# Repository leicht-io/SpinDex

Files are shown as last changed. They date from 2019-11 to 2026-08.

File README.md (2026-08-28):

# SpinDex
SpinDex is a small RPM measurement tool for the Beogram 4000 series.
The main focus is to verify that the turntable is restored correctly and maintains the correct speed over an extended period.
The code is written to run on the M5Stack StampS3 (ESP32-S3) but could easily be ported to other microcontrollers and architectures.

This mono repository is divided into multiple sub-repositories, explained below:

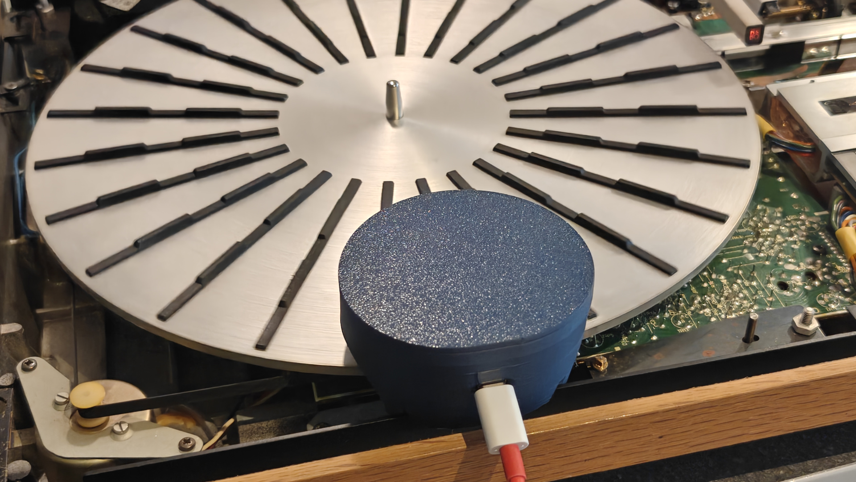
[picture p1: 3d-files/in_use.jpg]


### 3D Files (3d-files):
This folder contains all the 3D models.
- spindex_bottom.stl
- spindex_top.stl

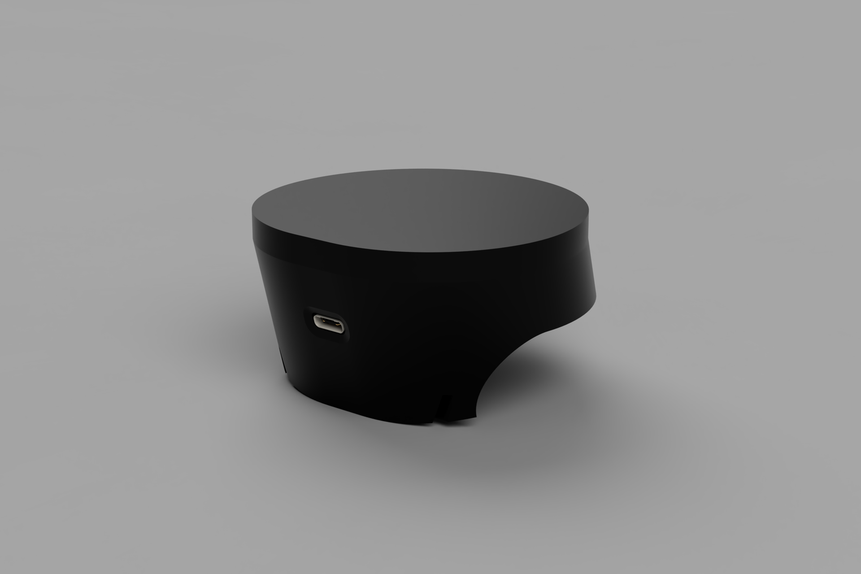
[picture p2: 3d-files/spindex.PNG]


---

### Web App (web-app)
This folder contains the web app. It connects to the controller over Bluetooth (Web Bluetooth — Chrome/Edge on desktop or Android, no install needed) and displays the live RPM as a temporal line graph. It's hosted publicly, free to use, at **https://spindex.leicht.io/**.

Features:
- Pair with the controller over Web Bluetooth, with automatic reconnect on a dropped connection so an unattended run rides out a transient disconnect.
- Start/stop tracking sessions, persisted locally in the browser (IndexedDB) — a page refresh or reconnect doesn't lose the running session.
- Keep multiple tracking sessions around and switch between them from the Trackings list, including revisiting past (stopped) sessions.
- Name a tracking when starting it, or rename it later from the Trackings list.
- Live stat tiles for current/average/max RPM and % deviation from the nominal 33⅓/45 RPM target, colour-coded by how far off spec.
- Selectable chart time window (Live 10 min / 1h / 6h / 12h / 24h / All), auto-bucketed to a fixed point budget so even a 24h session stays smooth to render.
- Gap-aware charting — a BLE disconnect or closed tab shows as a clearly marked gap in the plot rather than a misleading flat or interpolated line.
- CSV export of any tracking session for offline analysis.
- Delete old tracking sessions.
- Single dark, "precision-instrument" themed UI.

Unit tests for the pure logic (chart bucketing/gap detection, CSV export) run via `npm test`, see `web-app/package.json`.

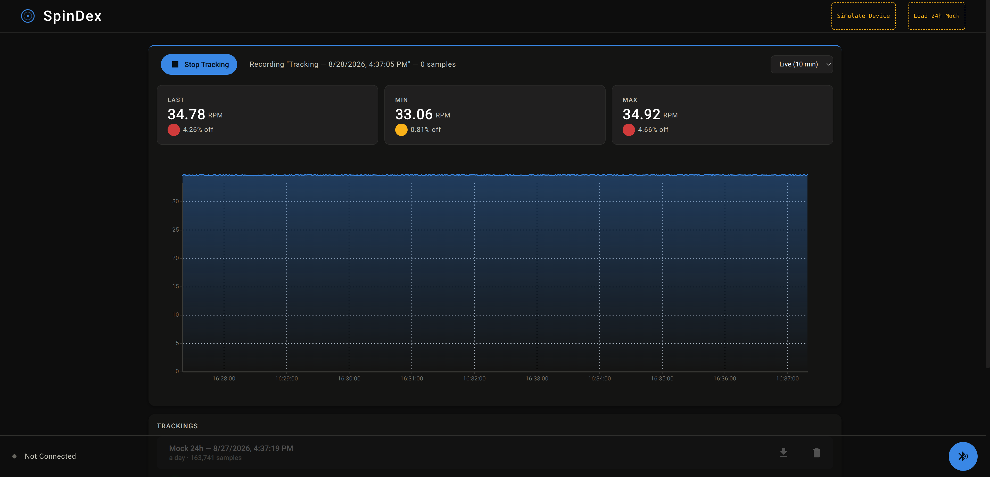
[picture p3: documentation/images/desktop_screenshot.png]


---

### µController Source Code (controller-source)
This folder contains the source code for the microcontroller. The RPM edge-counting/calculation logic is split out into a hardware-free class (`src/logic/RpmCounter`) with its own unit tests, runnable on the host (no board needed) via `pio test -e native`.

---

### Documentation (documentation)
This folder contains the [sensor pin setup and wiring diagram](documentation/pinSetup.md). The PCB schematics themselves live in `hardware/carrier-board`, below.

---

### Hardware (hardware/carrier-board)
This folder contains the custom carrier board PCB design (KiCad) that
piggybacks the M5Stack StampS3 module and the TCRT5000 IR sensor front end
on a single board. See its own [README](hardware/carrier-board/README.md)
for the schematic writeup, BOM, and what's left before fabrication.

---

Please note that this project is in progress and prone to change. The following tasks needs to be implemented before i consider the SpinDex finished.

- tests (started — see the web app's `npm test` and the µController's `pio test -e native`; coverage is still thin, mostly the pure logic so far).
- custom-made PCB (in progress, see `hardware/carrier-board` — not yet routed or fabricated).

Feel free to develop further on the project and create PRs if, necessary. I would be happy to cooperate with others on the device.

Blog posts with more pictures:

- https://leicht.io/articles/beotac-a-tachometer-for-the-beogram-4000-series
- https://leicht.io/articles/updates-to-beotac

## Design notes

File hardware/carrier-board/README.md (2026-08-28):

# SpinDex Carrier Board

A custom PCB that piggybacks the M5Stack STAMP-S3M module on one side and
implements the TCRT5000 reflective IR sensor + comparator circuit directly
on the other, replacing the hand-wired FC-51/TCRT5000 breakout + jumper
wires with a single board sized to mount precisely against the Beogram's
strobe ring.

Built with KiCad 9. Everything in this folder was generated by script (see
"How this was built" below) and validated with `kicad-cli` (ERC/DRC both
pass clean) — **but it has not been opened in the KiCad GUI or physically
verified yet.** Do the checks in "Before you fabricate" first.

## Files

- `carrier-board.kicad_pro` / `.kicad_sch` / `.kicad_pcb` — the project
- `spindex.kicad_sym` — custom symbols: `STAMP-S3M`, `TCRT5000`
- `spindex.pretty/STAMP-S3M_DIP28_P1.27mm.kicad_mod` — custom footprint
- `sym-lib-table` / `fp-lib-table` — project-local library table, adds only
  the `spindex` library; everything else (Device, Comparator, OptoDevice,
  Connector_JST, etc.) resolves from KiCad's standard global libraries

## What's verified vs. estimated

**Verified directly from primary sources:**
- STAMP-S3M's full 28-pin pinout (pin number → signal name) — read
  directly from M5Stack's own module schematic
  ([Sch_M5StampS3_v0.2.pdf](https://m5stack-doc.oss-cn-shenzhen.aliyuncs.com/522/Sch_M5StampS3_v0.2.pdf))
- 1.27mm pin pitch, 26×18×5mm module body (M5Stack docs/product listings)
- TCRT5000 pin assignment (1=Collector, 2=Emitter, 3=Anode, 4=Cathode) —
  read directly from the [Vishay TCRT5000 datasheet](https://www.vishay.com/docs/83760/tcrt5000.pdf)'s
  top-view pin diagram
- The `OptoDevice:Vishay_TCRT5000` footprint is KiCad's own standard
  library part for this exact component — not custom-made

**NOT verified — check before fabricating:**
- **Row-to-row pad spacing on `STAMP-S3M_DIP28_P1.27mm`, set to 15.24mm.**
  No source gives this dimension; it's sized to fit inside the module's
  known 18mm body width with plausible margin, nothing more. **Measure the
  actual module with calipers and update `ROW_SPACING` in
  `gen_footprint.py` (or edit the footprint directly) before ordering
  boards.** Getting this wrong means the module's pins won't line up with
  the holes.

## The circuit

- **Power:** none of this board's business, deliberately. The M5StampS3
  module (the assembled product, not just the bare chip-module inside it)
  has its own onboard USB-C connector and 5V→3.3V regulator — confirmed
  from M5Stack's own schematic, which shows the USB-C port, ESD protection,
  and DCDC regulator as part of the same board the 28-pin header lives on.
  Power it over USB-C like you would to flash it, and its `3V3` pin (typed
  `power_out` in the symbol, since the module is genuinely sourcing that
  rail) feeds the sensor circuit directly. `5V` on the header is a no-connect
  here — it's an available breakout on the module, not something this board
  drives. There's no separate power connector or regulator on this board at
  all; earlier drafts had a JST-PH power input and a bulk cap, both removed
  once it was clear the module's own USB-C already covers it.
- **Sensor front end:** D1 (TCRT5000) — R1 (220Ω) limits the IR LED
  current; R2 (10kΞ) pulls the phototransistor's collector up to 3V3,
  forming a voltage divider whose node (`PHOTO_C`) swings toward GND when
  a reflective bar is under the sensor.
- **Comparator:** U2 (LM393, referenced via its base `LM2903` symbol —
  same part, see below) compares `PHOTO_C` against a threshold set by
  RV1 (10kΩ trimmer, wired 3V3–GND with the wiper feeding the comparator's
  `-` input). Output idles HIGH (pulled up by R4) and drops LOW when a
  reflective bar is detected — **same polarity as the wired TCRT1000/FC-51
  setups this replaces, so `arduino_target.ino`'s edge-detection logic
  works unchanged.** The comparator's second (unused) gate has both inputs
  tied to GND so it can't float/oscillate; its output is left unconnected.
- **Status LED:** D2 + R3, lights when the sensor output is LOW (i.e. a
  bar is detected) — handy for bench-checking alignment without a scope.
- **EN/Boot pull-ups, no buttons:** R5 (10kΩ, `EN`) and R6 (10kΩ, `G0/Boot`)
  hold both pins at a defined HIGH so the module boots and runs normally.
  No manual reset/boot-select switches on this board — flashing means
  reconnecting USB-C to the module directly (same as any bare module),
  not pressing a button here.

### Why `Comparator:LM2903` instead of `LM393`

KiCad's `LM393` symbol is defined via `(extends "LM2903")` — it only holds
property overrides and depends on `LM2903`'s own graphics/pins to actually
render. Referencing `LM2903` directly avoids needing to also embed the
base symbol just to satisfy the alias, while remaining the same physically
interchangeable dual-comparator part; the schematic's `Value` field is set
to "LM393" so the BOM reads correctly.

## Layout

Two zones, as asked for — StampS3 on the left, TCRT5000 + comparator front
end on the right, on one board:

```
[R5]                        [D1 TCRT5000]
[R6]       [U1 STAMP-S3M]   [R1][R2]
                            [RV1]
                            [U2 LM393][C2]
                            [R4][R3]
                            [D2 status]
```

The board outline is currently just a bounding rectangle around all
components with room to breathe — **not a final shape.** Once the
enclosure is designed (or if it already exists in `../../3d-files/`),
reshape `Edge.Cuts` in the PCB editor so the sensor end sits where the
enclosure needs it relative to the platter, then trim the rest of the
board down from there.

## Before you fabricate

1. **Measure the actual STAMP-S3M module with calipers** and correct
   `ROW_SPACING` in `spindex.pretty/STAMP-S3M_DIP28_P1.27mm.kicad_mod` if
   it doesn't match 15.24mm.
2. **Open in KiCad and run "Update PCB from Schematic"** (Tools menu, or
   the equivalent toolbar button) — this syncs the netlist from the
   ERC-clean schematic onto the PCB and lights up the ratsnest. This
   wasn't done here on purpose: hand-duplicating the netlist into the PCB
   file risked a silent mismatch between the two; letting KiCad's own
   sync do it means there's exactly one source of truth (the schematic).
3. **Route the board.** Nothing is routed yet — only placed. A scripted
   auto-routing attempt was made (A* pathfinding with F.Cu/B.Cu+via
   fallback for congested spots) and got every net to *find* a path with
   0 unconnected nets, but kept surfacing new clearance/via-crowding
   violations faster than they could be cleanly resolved blindly —
   routing is fundamentally an interactive, visual-feedback problem
   (that's why every PCB tool has a live-DRC GUI for it) in a way
   placement and schematic capture weren't, and continuing to iterate
   on it without that feedback stopped being productive. With 12
   components and mostly low-speed signals this is a reasonable board to
   route by hand in an evening — KiCad's interactive router (push-and-
   shove, hotkey `X`) makes this fast once nets are synced from the
   schematic (step 2). There's no RF-critical routing here *except* keep
   the area over the STAMP-S3M module's antenna (top-right corner of its
   footprint, matching its silkscreen orientation) clear of copper and
   other components per M5Stack's own schematic — check their PDF for
   the exact keepout if you want to be precise about it. Also worth
   knowing: the layout was widened from an earlier pass to make room
   once real pad sizes were checked (routing revealed the initial
   spacing was tighter than the components actually need) — reasonable
   starting positions, not final.
4. **Tidy the schematic visually.** It's electrically correct (0 ERC
   violations) but was laid out programmatically — labels and component
   text overlap in places. Purely cosmetic; a few minutes of dragging
   things apart in the schematic editor fixes it, no netlist risk.
5. Reshape the board outline to the final enclosure, as above.
6. Re-run `kicad-cli sch erc` / `kicad-cli pcb drc` after any changes.

## BOM

| Ref | Part | Value | Footprint |
|---|---|---|---|
| U1 | M5Stack STAMP-S3M | — | `spindex:STAMP-S3M_DIP28_P1.27mm` |
| D1 | Vishay TCRT5000 | — | `OptoDevice:Vishay_TCRT5000` |
| U2 | LM393 (or LM2903) | dual comparator | `Package_DIP:DIP-8_W7.62mm` |
| RV1 | Trimmer potentiometer | 10kΩ | `Potentiometer_THT:Potentiometer_Bourns_3296W_Vertical` |
| R1, R3 | Resistor | 220Ω | `Resistor_THT:R_Axial_DIN0207_L6.3mm_D2.5mm_P10.16mm_Horizontal` |
| R2, R4, R5, R6 | Resistor | 10kΩ | same |
| C2 | Ceramic capacitor | 100nF | `Capacitor_THT:C_Disc_D3.0mm_W2.0mm_P2.50mm` |
| D2 | LED (status) | — | `LED_THT:LED_D3.0mm` |

All through-hole, hand-solder friendly. No power connector, regulator, or
buttons on this board — power and programming both go through the
M5StampS3 module's own USB-C port. Total BOM cost is a couple of dollars
in passives plus the STAMP-S3M module and TCRT5000 sensor themselves.

## How this was built

Every file here was generated by small Python scripts rather than
hand-typed — KiCad's `.kicad_sym`/`.kicad_sch`/`.kicad_pcb` S-expression
formats are precise enough that hand-authoring them risks subtle,
hard-to-spot mistakes (a wrong fill-type value, a flipped Y-axis sign
between library space and page space) that only show up as ERC/DRC
failures or, worse, silently-wrong connectivity. The generator scripts
aren't included in this folder (they were scratch tooling, not something
meant to be re-run), but the process was: generate → validate with
`kicad-cli sch erc` / `kicad-cli pcb drc` → fix → repeat until both came
back clean, plus rendering to SVG/PNG at each stage to visually sanity
check symbol/footprint graphics. Final state: **0 ERC violations, 0 DRC
violations.**

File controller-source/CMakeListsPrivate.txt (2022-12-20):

# !!! WARNING !!! AUTO-GENERATED FILE, PLEASE DO NOT MODIFY IT AND USE
# https://docs.platformio.org/page/projectconf/section_env_build.html#build-flags
#
# If you need to override existing CMake configuration or add extra,
# please create `CMakeListsUser.txt` in the root of project.
# The `CMakeListsUser.txt` will not be overwritten by PlatformIO.

set(CMAKE_CONFIGURATION_TYPES "nanoatmega328" CACHE STRING "Build Types reflect PlatformIO Environments" FORCE)

# Convert "Home Directory" that may contain unescaped backslashes on Windows

SET(CMAKE_C_COMPILER "$ENV{HOME}/.platformio/packages/toolchain-atmelavr/bin/avr-gcc")
SET(CMAKE_CXX_COMPILER "$ENV{HOME}/.platformio/packages/toolchain-atmelavr/bin/avr-g++")
SET(CMAKE_CXX_FLAGS "-fno-exceptions -fno-threadsafe-statics -fpermissive -std=gnu++11 -mmcu=atmega328p -Os -Wall -ffunction-sections -fdata-sections -flto")
SET(CMAKE_C_FLAGS "-std=gnu11 -fno-fat-lto-objects -mmcu=atmega328p -Os -Wall -ffunction-sections -fdata-sections -flto")

SET(CMAKE_C_STANDARD 11)
set(CMAKE_CXX_STANDARD 11)

if (CMAKE_BUILD_TYPE MATCHES "nanoatmega328")
    add_definitions(-DPLATFORMIO=60106)
    add_definitions(-DARDUINO_AVR_NANO)
    add_definitions(-DF_CPU=16000000L)
    add_definitions(-DARDUINO_ARCH_AVR)
    add_definitions(-DARDUINO=10808)
    add_definitions(-D__AVR_ATmega328P__)

    include_directories("${CMAKE_CURRENT_LIST_DIR}/include")
    include_directories("${CMAKE_CURRENT_LIST_DIR}/src")
    include_directories("$ENV{HOME}/.platformio/packages/framework-arduino-avr/cores/arduino")
    include_directories("$ENV{HOME}/.platformio/packages/framework-arduino-avr/variants/eightanaloginputs")
    include_directories("$ENV{HOME}/.platformio/packages/framework-arduino-avr/libraries/EEPROM/src")
    include_directories("$ENV{HOME}/.platformio/packages/framework-arduino-avr/libraries/HID/src")
    include_directories("$ENV{HOME}/.platformio/packages/framework-arduino-avr/libraries/SPI/src")
    include_directories("$ENV{HOME}/.platformio/packages/framework-arduino-avr/libraries/SoftwareSerial/src")
    include_directories("$ENV{HOME}/.platformio/packages/framework-arduino-avr/libraries/Wire/src")
    include_directories("$ENV{HOME}/.platformio/packages/toolchain-atmelavr/lib/gcc/avr/7.3.0/include-fixed")
    include_directories("$ENV{HOME}/.platformio/packages/toolchain-atmelavr/lib/gcc/avr/7.3.0/include")
    include_directories("$ENV{HOME}/.platformio/packages/toolchain-atmelavr/avr/include")

    FILE(GLOB_RECURSE EXTRA_LIB_SOURCES
        ${CMAKE_CURRENT_LIST_DIR}/.pio/libdeps/nanoatmega328/*.*
    )
endif()

FILE(GLOB_RECURSE SRC_LIST
    ${CMAKE_CURRENT_LIST_DIR}/src/*.*
    ${CMAKE_CURRENT_LIST_DIR}/lib/*.*
    ${CMAKE_CURRENT_LIST_DIR}/test/*.*
)

list(APPEND SRC_LIST ${EXTRA_LIB_SOURCES})

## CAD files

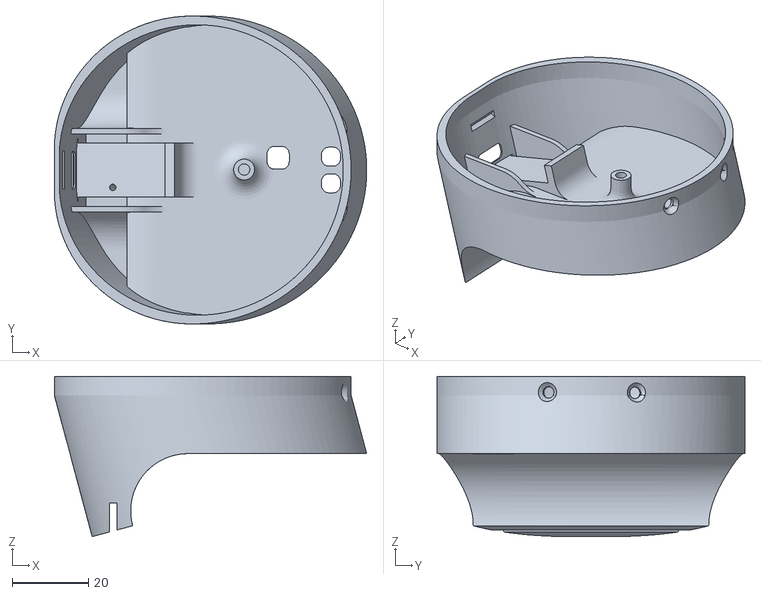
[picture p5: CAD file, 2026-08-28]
3d-files/spindex_bottom.stl
81.9 x 80.7 x 42.0

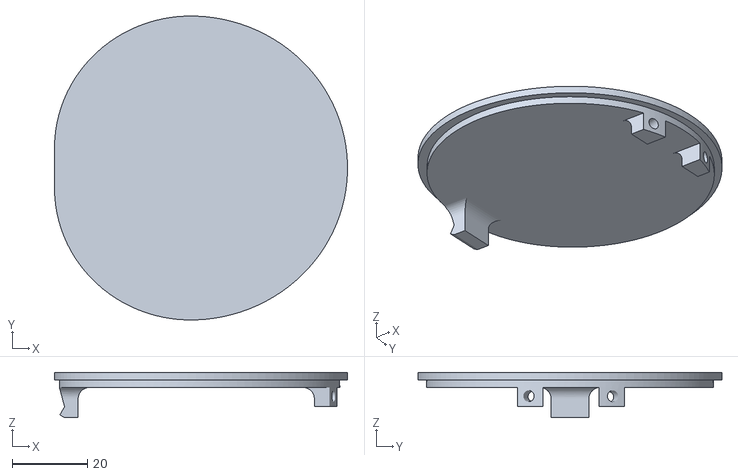
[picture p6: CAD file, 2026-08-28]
3d-files/spindex_top.stl
77.8 x 80.7 x 12.0

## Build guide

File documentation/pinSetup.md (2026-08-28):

# Pin Setup

**Board:** M5Stack StampS3 (ESP32-S3)
**IR sensor:** FC-51 IR obstacle avoidance module (LM393 comparator, ~2-30cm adjustable range)

## Wiring

| FC-51 pin | StampS3 pin | Notes |
|---|---|---|
| VCC | `3V3` | Wired directly to the 3V3 rail, **not** a GPIO. Measured draw is ~23mA at 3.3V — close enough to GPIO source limits to keep it on the dedicated rail. |
| GND | `GND` | |
| OUT | `G1` | Digital input (already comparator-conditioned by the module, LM393). Idles HIGH with no reflection; drops LOW when the IR beam bounces back off a reflective surface. |

```mermaid
graph LR
    subgraph StampS3["M5Stack StampS3"]
        S3_3V3["3V3"]
        S3_GND["GND"]
        S3_G1["G1"]
    end
    subgraph FC51["FC-51"]
        F_VCC["VCC"]
        F_GND["GND"]
        F_OUT["OUT"]
    end
    S3_3V3 -->|3-6V| F_VCC
    S3_GND --- F_GND
    S3_G1 -->|reads| F_OUT
```

The sensor is aimed at the 24 alternating dark/reflective bars on the Beogram platter's strobe ring; each HIGH transition on `G1` marks one bar crossed.

### Mounting note

The FC-51's beam is ~35° wide, considerably wider than a focused sensor like the TCRT1000 (0.2-4mm range) it replaced. Mount it toward the **near end** of its adjustable range (a centimeter or two, not the full 30cm) and use the onboard trimpot to set a tight threshold rather than maximum sensitivity — the goal is a clean single-bar edge, not detecting several bars at once, which would blur transitions and throw off the RPM count. These LM393-based modules are also more sensitive to bright ambient/IR light than sensors with a daylight-blocking filter, so avoid testing in direct sunlight.

### Previously: TCRT1000

The original build used the [Adafruit STEMMA Reflective Photo Interrupt Sensor (TCRT1000)](https://www.adafruit.com/product/5913), wired VIN→3V3, GND→GND, SIG→G1 with identical polarity (idle HIGH, drops on reflection). It was replaced due to its very tight 0.2-4mm required sensing distance, which made consistent mounting difficult. If reverting, no firmware changes are needed — only the wiring.

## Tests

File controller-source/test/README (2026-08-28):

Unit tests for the µController source.

Run on the host, no board or hardware attached:

    pio test -e native

`test_rpm_counter/` exercises `src/logic/RpmCounter` — the tachometer
edge-counting and RPM calculation pulled out of `arduino_target.ino`'s
TimerHandler0 into a plain C++ class with no Arduino.h dependency, so it
can run natively instead of needing a real sensor and platter to test
against. `arduino_target.ino` itself, and anything under `src/data`, depend
on Arduino.h/BLE and can't be built for the `native` environment — see
`platformio.ini`'s `build_src_filter` for the `[env:native]` env.

More on PlatformIO Unit Testing: https://docs.platformio.org/page/plus/unit-testing.html

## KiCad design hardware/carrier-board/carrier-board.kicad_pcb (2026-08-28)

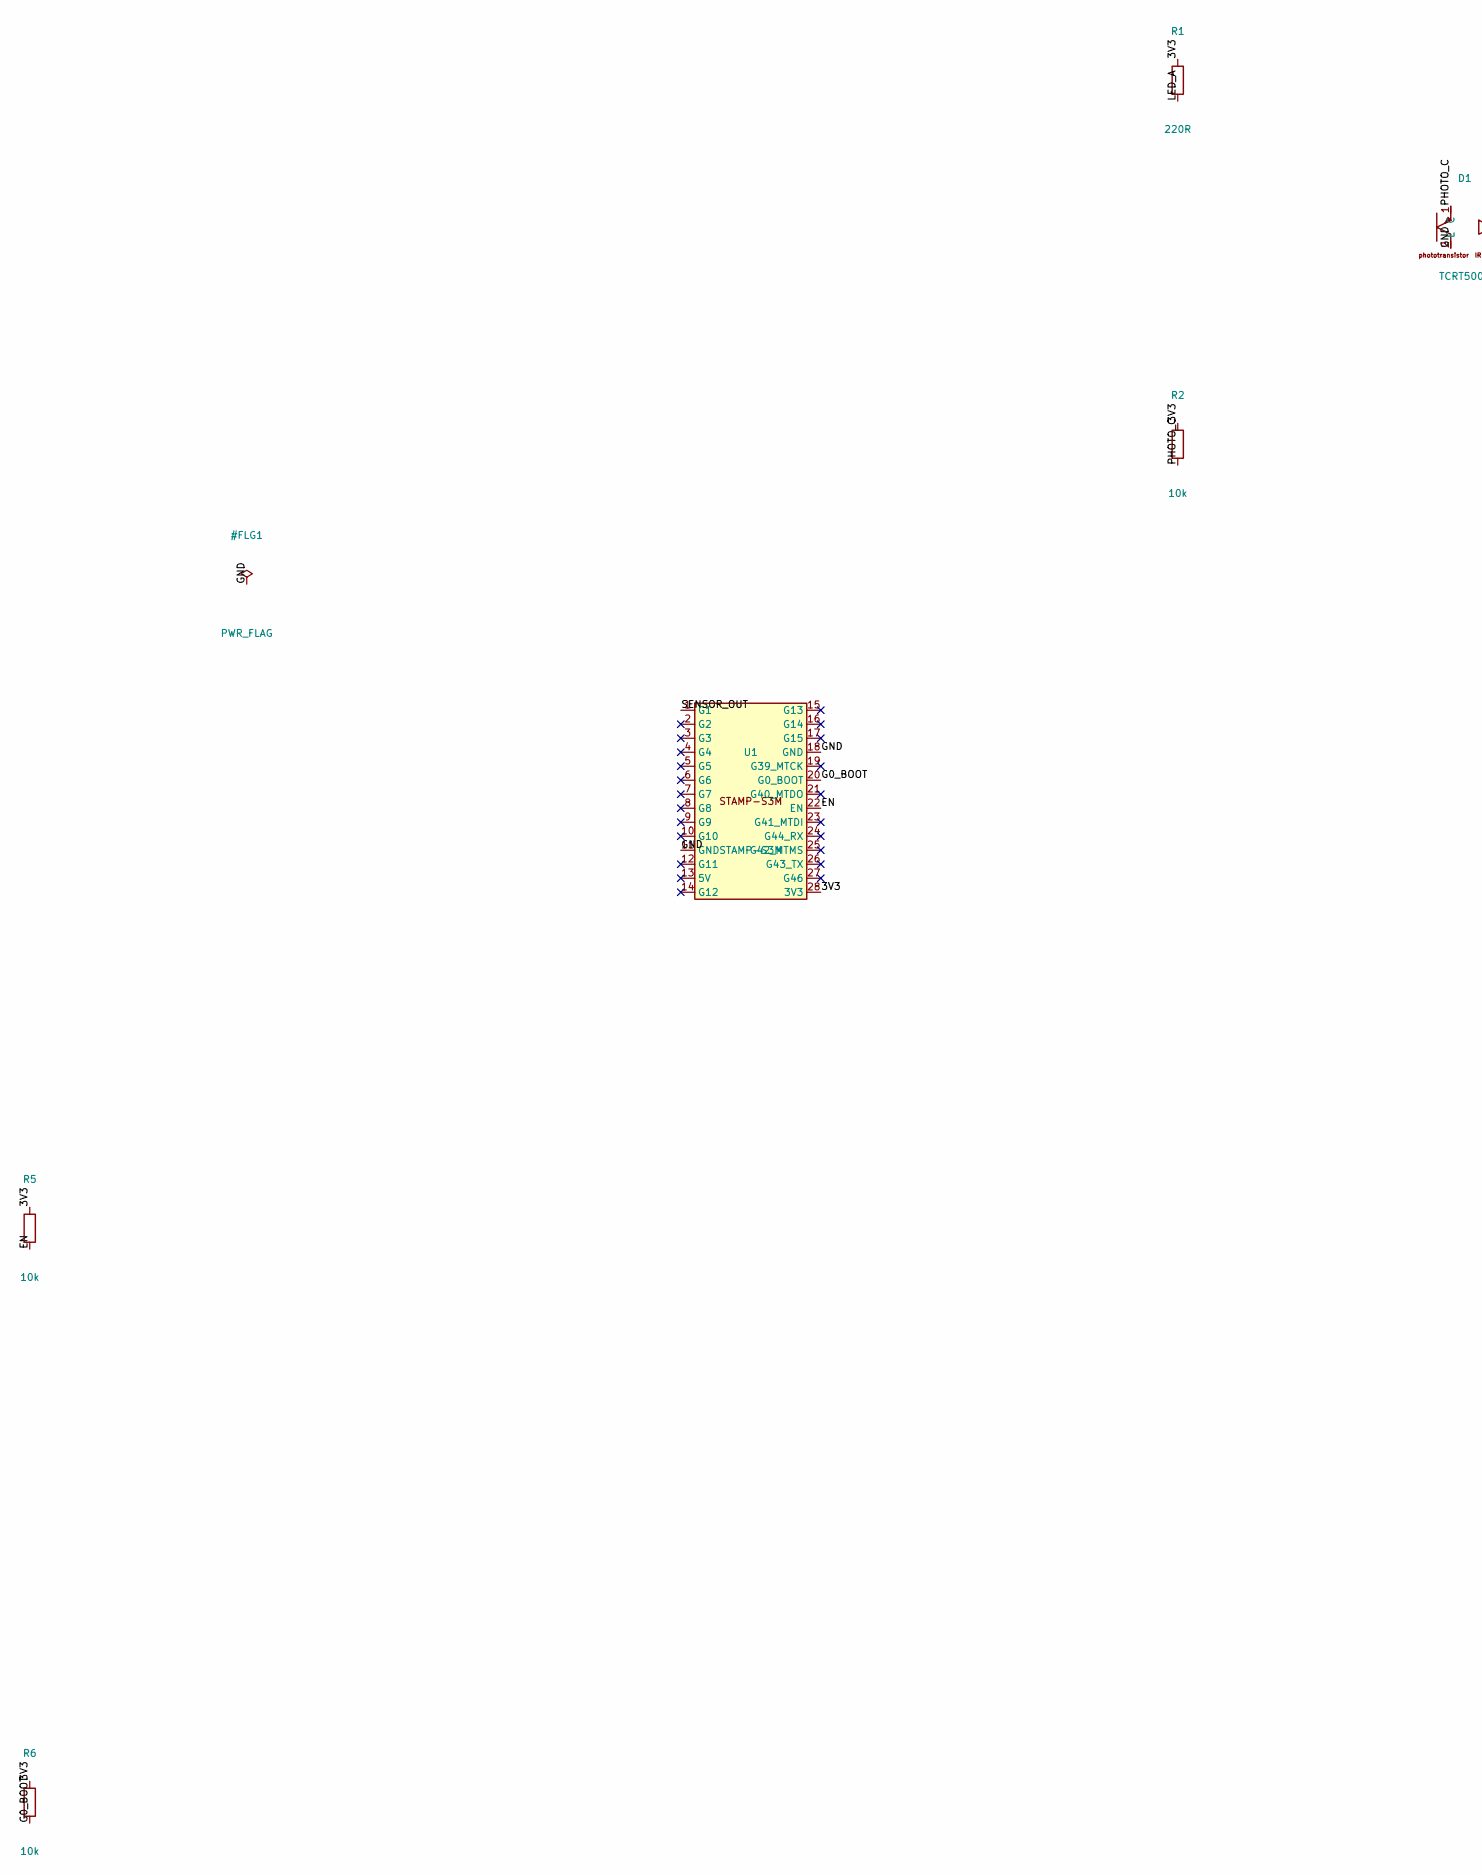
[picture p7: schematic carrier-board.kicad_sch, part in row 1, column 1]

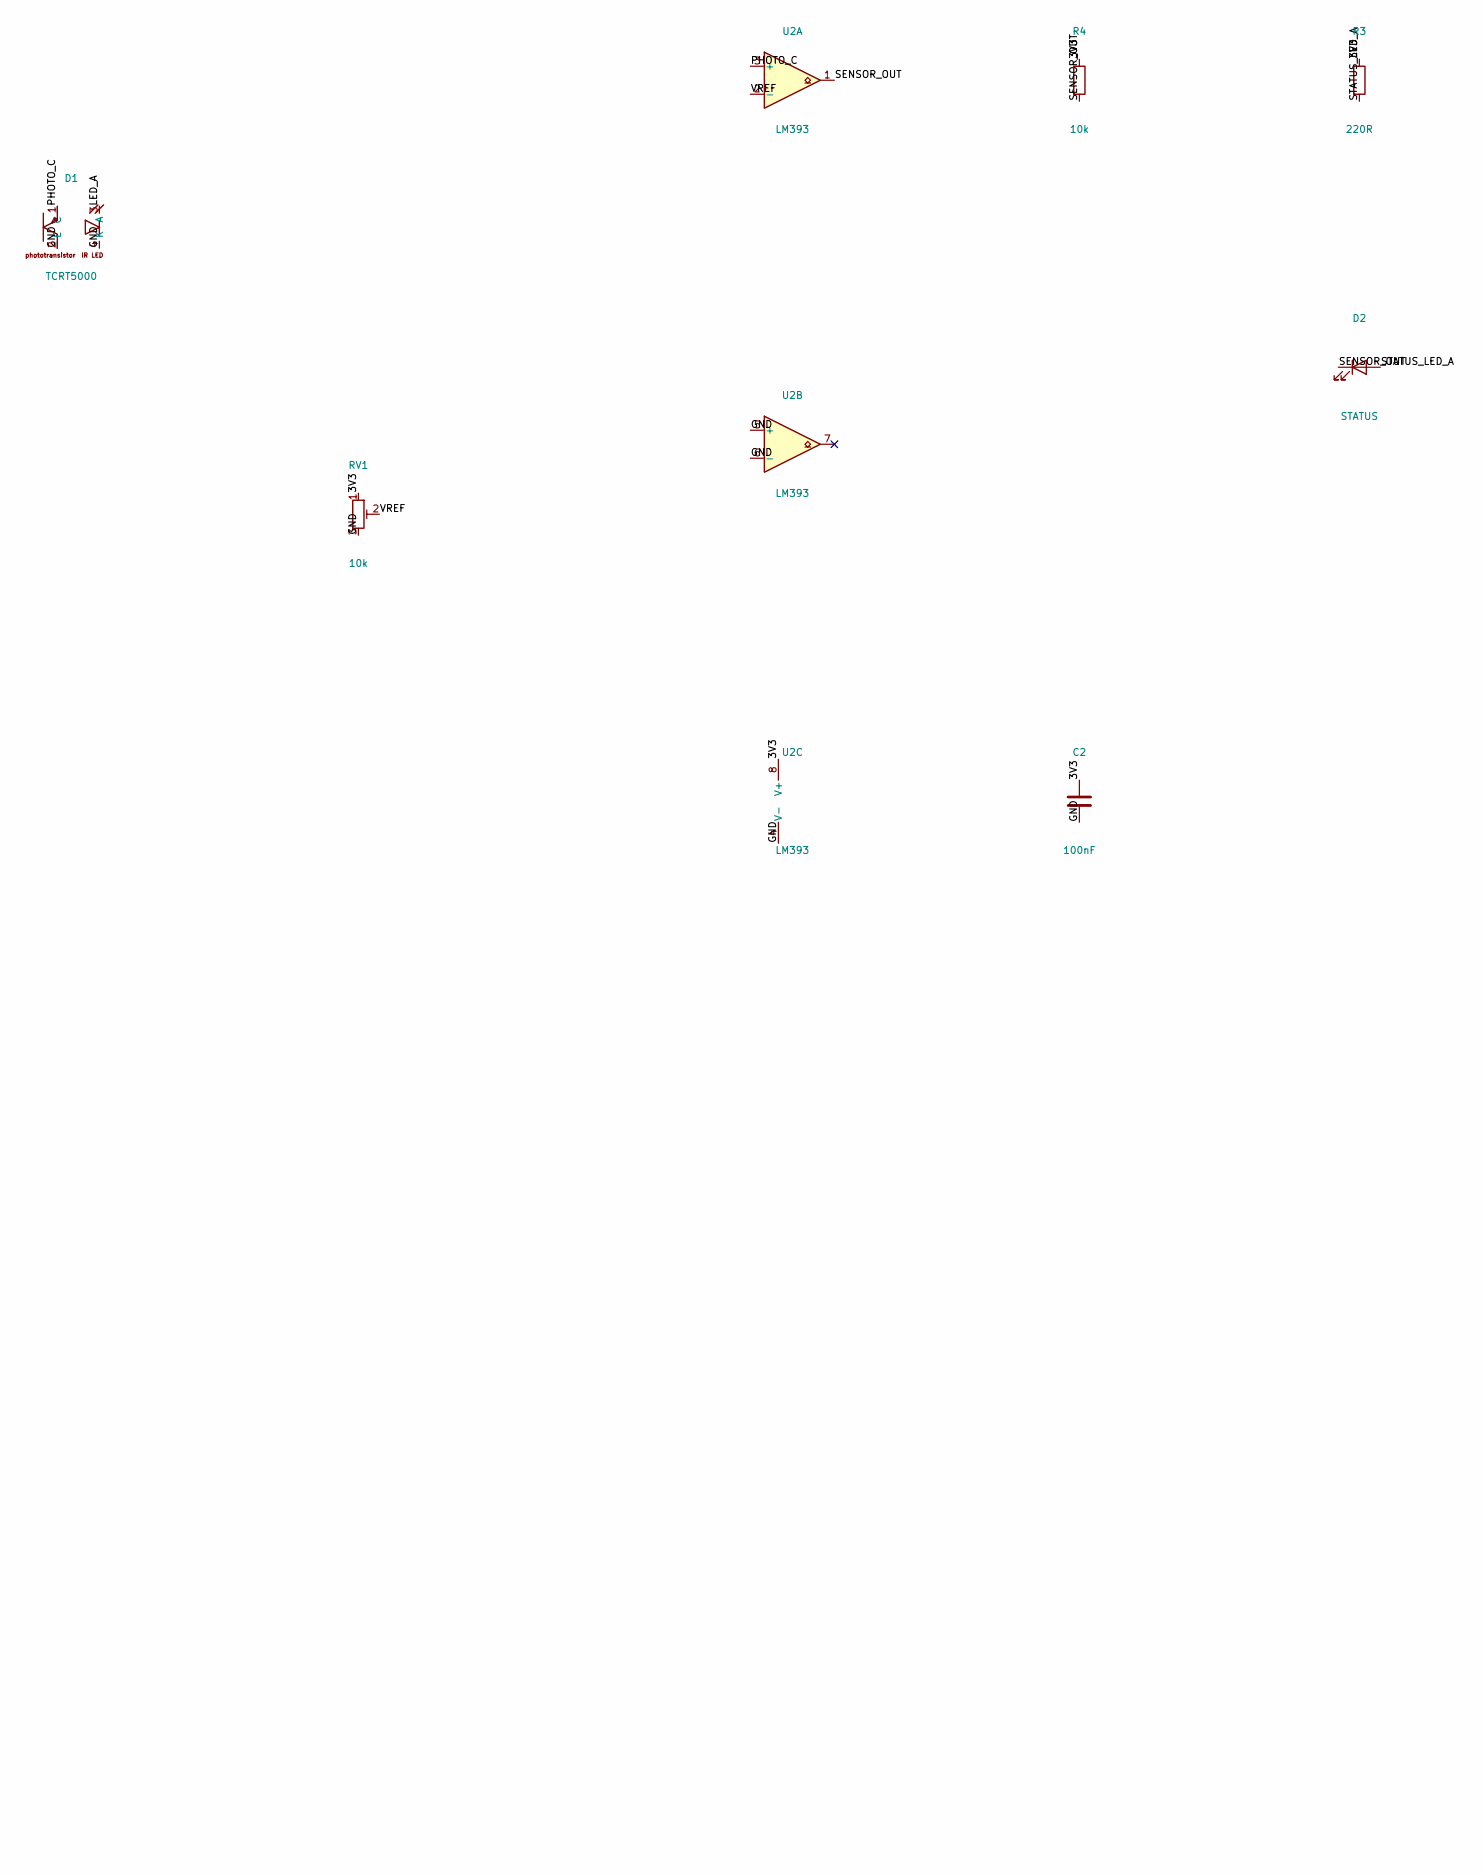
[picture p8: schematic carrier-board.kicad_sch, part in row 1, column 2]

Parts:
C2: 100nF; C_Disc_D3.0mm_W2.0mm_P2.50mm
D1: TCRT5000; Vishay_TCRT5000
D2: STATUS; LED_D3.0mm
R1, R3: 220R; R_Axial_DIN0207_L6.3mm_D2.5mm_P10.16mm_Horizontal
R2, R4, R5, R6: 10k; R_Axial_DIN0207_L6.3mm_D2.5mm_P10.16mm_Horizontal
RV1: 10k; Potentiometer_Bourns_3296W_Vertical
U1: STAMP-S3M; Stamp-S3-SMD
U2: LM393; DIP-8_W7.62mm

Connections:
/3V3: C2.1, R1.1, R2.1, R3.1, R4.1, R5.1, R6.1, RV1.1, U1.28 (3V3), U2.8 (V+)
/EN: R5.2, U1.22 (EN)
/G0_BOOT: R6.2, U1.20 (G0_BOOT)
/GND: C2.2, D1.2 (E), D1.4 (K), RV1.3, U1.11 (GND), U1.18 (GND), U2.4 (V-), U2.5 (+), U2.6 (-)
/LED_A: D1.3 (A), R1.2
/PHOTO_C: D1.1 (C), R2.2, U2.3 (+)
/SENSOR_OUT: D2.1 (K), R4.2, U1.1 (G1), U2.1
/STATUS_LED_A: D2.2 (A), R3.2
/VREF: RV1.2, U2.2 (-)

Board: 2 copper layers, 12 parts (1 on the bottom side), 9 nets, no tracks yet.

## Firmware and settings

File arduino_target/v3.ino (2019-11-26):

#include <SPI.h>
#include <Wire.h>
#include <Adafruit_GFX.h>
#include <Adafruit_SSD1306.h>
#include <TimerOne.h>

const int IRSensorPin = 2;  // the number of the IR sensor input pin

int inputState;                          // the current state from the input pin
int lastInputState = LOW;        // the previous InputState from the input pin
long lastDebounceTime = 0;   // the last time the output pin was toggled
long debounceDelay = 5;        // the debounce time; increase if the output flickers
long time;
long endTime;
long startTime;
float RPM = 0.0;
float lnTime = 0;
boolean logRPMToScreen = false;
unsigned int graph[66];
unsigned int nextGraphIndex = 0;

#define SCREEN_WIDTH 128
#define SCREEN_HEIGHT 32

#define OLED_RESET     4 // Reset pin # (or -1 if sharing Arduino reset pin) // Declaration for an SSD1306 display connected to I2C (SDA, SCL pins)
Adafruit_SSD1306 display(SCREEN_WIDTH, SCREEN_HEIGHT, &Wire, OLED_RESET);

static const unsigned char PROGMEM logo_bmp[] ={
 0x00, 0x00, 0x00, 0x00, 0x00, 0x00, 0x00, 0x00, 0x00, 0x00, 0x00, 0x00, 0x00, 0x00, 0x00, 0x00,
  0x00, 0x03, 0xbc, 0x00, 0x00, 0x00, 0x00, 0x00, 0x00, 0x00, 0x00, 0x00, 0x00, 0x00, 0x00, 0x00,
  0x00, 0x1d, 0xbd, 0xe0, 0x00, 0x00, 0x00, 0x00, 0x00, 0x00, 0x00, 0x00, 0x00, 0x00, 0x00, 0x00,
  0x00, 0x3d, 0xfd, 0xe8, 0x00, 0x00, 0x00, 0x00, 0x00, 0x00, 0x00, 0x00, 0x00, 0x00, 0x00, 0x00,
  0x01, 0xfd, 0xff, 0xfc, 0x00, 0x00, 0x00, 0x00, 0x00, 0x80, 0x06, 0x00, 0x00, 0x00, 0x00, 0x00,
  0x03, 0xff, 0xfb, 0xfc, 0x00, 0x3e, 0x1f, 0x18, 0x18, 0x87, 0xc6, 0x60, 0x70, 0x02, 0x00, 0x00,
  0x05, 0xfe, 0xfb, 0x7b, 0x00, 0x33, 0x11, 0x3c, 0x38, 0x8c, 0x66, 0x70, 0x70, 0x02, 0x00, 0x00,
  0x0e, 0xf6, 0xfb, 0xf7, 0xc0, 0x31, 0x11, 0xbc, 0x38, 0x98, 0x26, 0x70, 0xf0, 0xc7, 0x86, 0x04,
  0x1f, 0xfa, 0xfe, 0xef, 0x80, 0x31, 0x11, 0xbc, 0x28, 0x10, 0x30, 0x58, 0xb3, 0xe7, 0xdf, 0x3e,
  0x27, 0xdf, 0x25, 0xde, 0x60, 0x3f, 0x13, 0x36, 0x68, 0x10, 0x30, 0x58, 0xb2, 0x33, 0x31, 0x30,
  0x3d, 0xfd, 0x25, 0xf9, 0xe0, 0x3e, 0x1e, 0x36, 0x48, 0x10, 0x30, 0x49, 0xb3, 0xf2, 0x3f, 0xb0,
  0x7e, 0x7a, 0xfa, 0xe7, 0xf0, 0x33, 0x18, 0x32, 0xc8, 0x10, 0x20, 0x4d, 0x33, 0xf2, 0x3f, 0x30,
  0x1f, 0xcf, 0xff, 0x9f, 0x00, 0x31, 0x10, 0x33, 0xc8, 0x18, 0x60, 0x4f, 0x32, 0x02, 0x30, 0x30,
  0x60, 0xf7, 0xff, 0x70, 0xf0, 0x31, 0x90, 0x31, 0x88, 0x0c, 0xe0, 0x46, 0x33, 0x03, 0x10, 0x30,
  0x7f, 0x07, 0xff, 0x0f, 0xf0, 0x31, 0x90, 0x31, 0x88, 0x07, 0x80, 0x46, 0x31, 0xf3, 0x9f, 0x30,
  0x7f, 0xff, 0xff, 0xff, 0xe0, 0x00, 0x00, 0x00, 0x00, 0x00, 0x00, 0x00, 0x00, 0x00, 0x00, 0x00,
  0x00, 0x07, 0x8f, 0x80, 0x20, 0x00, 0x00, 0x00, 0x00, 0x00, 0x00, 0x00, 0x00, 0x00, 0x00, 0x00,
  0x7f, 0xf7, 0xff, 0x1f, 0xf0, 0x00, 0x00, 0x00, 0x00, 0x00, 0x00, 0x00, 0x00, 0x00, 0x00, 0x00,
  0x7f, 0x0f, 0xff, 0xe1, 0xf0, 0x00, 0x00, 0x00, 0x00, 0x00, 0x00, 0x00, 0x00, 0x00, 0x00, 0x00,
  0x70, 0xf7, 0xff, 0x3f, 0x00, 0x00, 0x00, 0x00, 0x00, 0x00, 0x00, 0x00, 0x00, 0x00, 0x00, 0x00,
  0x0f, 0x99, 0xfe, 0xe7, 0xf0, 0x00, 0x00, 0x00, 0x00, 0x00, 0x00, 0x00, 0x00, 0x00, 0x00, 0x00,
  0x3f, 0x7e, 0x65, 0x7b, 0xf0, 0x00, 0x00, 0x00, 0x00, 0x00, 0x00, 0x00, 0x00, 0x00, 0x00, 0x00,
  0x3c, 0xed, 0x65, 0xde, 0x60, 0x00, 0x00, 0x00, 0x00, 0x00, 0x00, 0x02, 0x06, 0x08, 0x00, 0x80,
  0x03, 0xdf, 0x7a, 0xef, 0x80, 0x00, 0x00, 0x00, 0x00, 0x00, 0x00, 0x02, 0x00, 0x0c, 0x20, 0x00,
  0x0f, 0xbb, 0xfb, 0x77, 0xc0, 0x00, 0x00, 0x00, 0x00, 0x00, 0x00, 0x02, 0x76, 0xff, 0x78, 0x9e,
  0x0f, 0x7e, 0xeb, 0x7b, 0x80, 0x00, 0x00, 0x00, 0x00, 0x00, 0x00, 0x02, 0x96, 0x8d, 0xa0, 0xb2,
  0x06, 0xf6, 0xed, 0xfc, 0x00, 0x00, 0x00, 0x00, 0x00, 0x00, 0x00, 0x02, 0xf6, 0x88, 0xa0, 0xb2,
  0x01, 0xfe, 0xfd, 0xfe, 0x00, 0x00, 0x00, 0x00, 0x00, 0x00, 0x00, 0x02, 0x86, 0x88, 0xa0, 0xb2,
  0x00, 0xdf, 0xfd, 0xec, 0x00, 0x00, 0x00, 0x00, 0x00, 0x00, 0x00, 0x02, 0xf6, 0xe8, 0xba, 0x9c,
  0x00, 0x3d, 0xfd, 0xf0, 0x00, 0x00, 0x00, 0x00, 0x00, 0x00, 0x00, 0x00, 0x00, 0x00, 0x00, 0x00,
  0x00, 0x0d, 0xfe, 0x80, 0x00, 0x00, 0x00, 0x00, 0x00, 0x00, 0x00, 0x00, 0x00, 0x00, 0x00, 0x00,
  0x00, 0x00, 0xf8, 0x00, 0x00, 0x00, 0x00, 0x00, 0x00, 0x00, 0x00, 0x00, 0x00, 0x00, 0x00, 0x00
};


static const unsigned char PROGMEM thumbsUp[] = {
  0x00, 0x00, 0x00, 0x00, 0x00, 0x00, 0x00, 0x01, 0xc0, 0x00, 0x07, 0xc0, 0x00, 0x0f, 0x00, 0x30,
0x3e, 0x00, 0x78, 0x7c, 0x00, 0x3f, 0xf0, 0x00, 0x1f, 0xe0, 0x00, 0x07, 0x80, 0x00, 0x03, 0x00,
0x00, 0x00, 0x00, 0x00, 0x00, 0x00, 0x00
};

static const unsigned char PROGMEM thumbsDown[] = {
0x00, 0x00, 0x00, 0x38, 0x03, 0x80, 0x7e, 0x0f, 0xc0, 0x3f, 0x1f, 0x80, 0x0f, 0xfe, 0x00, 0x07,
0xfc, 0x00, 0x03, 0xf8, 0x00, 0x07, 0xfc, 0x00, 0x0f, 0xfe, 0x00, 0x3f, 0x1f, 0x80, 0x7c, 0x07,
0xc0, 0x38, 0x03, 0x80, 0x00, 0x00, 0x00
};

String zeroPad(double RPM) {
 String RPMToReturn = String(RPM);

 if(RPMToReturn.length() == 4) {
  int indexOfSeperator = RPMToReturn.indexOf(".");
  if(indexOfSeperator == 1) {
    return "0" + RPMToReturn;
  } else if(indexOfSeperator == 2) {
    return RPMToReturn + "0";
  }
 }

return RPMToReturn;
}

void setup(void) {
  pinMode(IRSensorPin, INPUT);

  Serial.begin(9600);

  endTime = 0;
  Timer1.initialize(1000000);  // Set the timer to 60 rpm, 1,000,000 microseconds (1 second)
  Timer1.attachInterrupt(timerIsr);  // Attach the service routine here

  initializeDisplay();
}


void updateScreen(float RPM) {
  display.clearDisplay();

  display.setTextSize(2); // Draw 2X-scale text
  display.setTextColor(WHITE);
  display.setCursor(2, 2);
  display.println(zeroPad(RPM));

  display.setTextSize(1);
  display.setCursor(65, 2);
  display.println("RPM");

  display.drawLine(0 , 18, 128, 18, WHITE);
  display.drawLine(90 , 2, 90, 15, WHITE);

  if(RPM > 33 && RPM < 33.5) {
    display.drawBitmap(100,3,thumbsUp, 19, 13, 1);
  } else {
    display.drawBitmap(100,3,thumbsDown, 19, 13, 1);
  }

  if(RPM <= 10) {
   graph[nextGraphIndex] = 1;
  } else if(RPM > 10  && RPM <= 20) {
    graph[nextGraphIndex] = 2;
  } else if(RPM > 20 && RPM <= 30){
    graph[nextGraphIndex] = 4;
  } else if(RPM > 30 && RPM <= 40) {
    graph[nextGraphIndex] = 6;
  }else if(RPM > 40) {
    graph[nextGraphIndex] = 8;
  }

  nextGraphIndex++;
  if(nextGraphIndex > 67) {
    nextGraphIndex = 0;
  }

  for(int i = 0; i < 66; i++) {
    display.drawLine((1 * i) * 2 + 1, 28, (1 * i * 2) + 1,  28 - graph[i], WHITE);
  }

  display.display();
}

void initializeDisplay() {
  if(!display.begin(SSD1306_SWITCHCAPVCC, 0x3C)) { // Address 0x3C for 128x32, SSD1306_SWITCHCAPVCC = generate display voltage from 3.3V internally
    Serial.println(F("SSD1306 allocation failed"));
    for(;;); // Don't proceed, loop forever
  }

  display.clearDisplay();
  display.drawBitmap(0, 0, logo_bmp, 128, 32, 1);
  display.display();
  delay(5000);

  display.clearDisplay();
  updateScreen(0.0);
}

// ---------------------------------------------------------------
void loop(void) {
  time = millis();
  int currentSwitchState = digitalRead(IRSensorPin);

  if (currentSwitchState != lastInputState) {
    lastDebounceTime = millis();
  }

  if ((millis() - lastDebounceTime) > debounceDelay) {
    if (currentSwitchState != inputState) {
      inputState = currentSwitchState;
      if (inputState == LOW) {
        calculateRPM(); // Real RPM from sensor
      }
    }
  }
  lastInputState = currentSwitchState;
}

// ---------------------------------------------------------------
void calculateRPM() {
  startTime = lastDebounceTime;
  lnTime = startTime - endTime;
  RPM = (60000 / (lnTime)) / 24.0; // 24 dark bars on BG4002
  endTime = startTime;
}

void timerIsr()
{
  time = millis() / 1000;

  Serial.println(RPM);

  logRPMToScreen = true;

   delay(500);


  RPM = 0.0;
}

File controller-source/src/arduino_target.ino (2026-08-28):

#define BLUETOOTH_ENABLED           true
#define SERIAL_ENABLED              true
#define TIMER0_INTERVAL_MS          1
#define _TIMERINTERRUPT_LOGLEVEL_   0

#include "data/SerialComm.h"
#include "data/Bluetooth.h"
#include "logic/RpmCounter.h"
#include "ESP32TimerInterrupt.h"

const long baudRate = 115200;
// FC-51 IR obstacle avoidance module (LM393 comparator, ~2-30cm
// adjustable range via onboard trimpot).
// OUT -> G1. VCC -> 3V3 rail directly: measured draw is ~23mA at
// 3.3V, close enough to GPIO source limits that it's kept on the
// dedicated rail rather than a pin, same as the TCRT1000 it replaced.
// Output idles HIGH (no reflection) and drops LOW when a reflective
// bar is detected -- same polarity as the TCRT1000, so no logic
// change was needed here when swapping sensors.
const byte irSensorPin = 1; // G1 on M5Stack StampS3

// Edge-counting + RPM math itself lives in RpmCounter (src/logic), kept
// free of Arduino.h so it can be unit-tested on the host (see
// test/test_rpm_counter) -- this .ino only wires it up to the real GPIO
// pin and clock.
RpmCounter rpmCounter(/* stepsPerRevolution */ 24, /* stallTimeoutMs */ 1000);

TaskHandle_t emitRPMTask;
SerialComm serialComm = SerialComm();
Bluetooth bluetooth = Bluetooth();
ESP32Timer ITimer0(0);

void initialDevice() {
    if(SERIAL_ENABLED) {
        Serial.begin(baudRate);
    }

    if(BLUETOOTH_ENABLED) {
        bluetooth.init();
    }
}

 void emitRPMLoop(void *pvParameters) {
    for (;;) {
        emitRPM(rpmCounter.rpm());
        bluetooth.checkConnection();

        delay(500);
    }
}

bool IRAM_ATTR TimerHandler0(void * timerNo) {
    rpmCounter.update(digitalRead(irSensorPin) == HIGH, millis());

    return true;
}

void setup(void) {
    pinMode(irSensorPin, INPUT);
    initialDevice();

	// Setting up interrupt
	if (ITimer0.attachInterruptInterval(TIMER0_INTERVAL_MS * 100, TimerHandler0)) {
		Serial.print(F("Starting  ITimer0, millis() = "));
		Serial.println(millis());
	} else {
		Serial.println(F("Can't start ITimer0. Select another freq. or timer"));
    }

   xTaskCreatePinnedToCore(emitRPMLoop, "emitRPMTask", 10000, NULL, 1, &emitRPMTask, 1);
}

void emitRPM(float RPM) {
    if(SERIAL_ENABLED) {
        serialComm.print(RPM);
    }

    if(BLUETOOTH_ENABLED) {
        bluetooth.sendValue(RPM);
    }
}

void loop() {
}

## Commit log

2019-11-11 updated source for arduino
2019-11-27 added working copy of arduino code.
2019-11-27 fix: added temperature to API structure.
2022-11-30 chore: refactored solution.
    [astreaus_body_v1.stl, astreaus_bottom_v1.stl, astreaus_led_v1.stl]
2022-12-21 fix: updated RPM calculations.
    [arduino_target.ino]
2022-12-22 feat: (WIP) added multicore support for ESP32 and ST7735 SPI display.
2023-12-26 fix: getting ready for headless.
    [arduino_target.ino]
2023-12-30 fix: cleaned solution and made it ready for web BLE.
    [arduino_target.ino]
2026-08-05 feat: switch to M5Stack StampS3 and TCRT1000 IR sensor, drop display
    - Build only the m5stack-stamps3 PlatformIO environment; remove the
    esp32doit-devkit-v1 target.
    - Remove the on-device display entirely (Display, StringUtils) since
    RPM readout now relies solely on Bluetooth; drop the now-unneeded
    Adafruit GFX/ST7735 lib deps.
    - Rewire the IR sensor for the Adafruit STEMMA Reflective Photo
    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
2026-08-05 fix: align web-app and root docs with SpinDex rename
    - web-app BLE device name filter still said "Astraeus" (leftover from
    the mono-repo's old name), so the browser could never find the
    firmware, which advertises as "SpinDex".
    - initBluetooth() called connectToDevice() and then duplicated its
    entire connection chain inline, triggering two separate Web
    Bluetooth device pickers per click; the duplicate (and only
    complete) chain is now the single connectToDevice() implementation.
    - README's 3D-files list and both embedded image links were stale:
    it named files that don't exist (spindex_body_v1.stl /
    spindex_bottom_v1.stl vs. the actual astreaus_*.stl files, missing
    the LED model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
2026-08-05 fix(web-app): correct Web Bluetooth API usage against spec
    - The device disconnect listener was registered on
    'gattservicedisconnected', which is not a real event — the spec name
    is 'gattserverdisconnected' (BluetoothDevice). Since it never fired,
    the UI never noticed the sensor disconnecting: `connected` stayed
    true and stale data stuck around after the device went away.
    - The connectToDevice() catch block only handled a rejection where
    `typeof error === "string"`, but requestDevice()/gatt.connect()
    reject with a DOMException (e.g. NotFoundError on chooser cancel),
    never a plain string — so the branch was dead and every connection
    failure (cancel, adapter off, GATT error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
2026-08-05 fix(web-app): type BLEContext against @types/web-bluetooth
    Added @types/web-bluetooth and replaced the any-casts in BLEContext
    with the real BluetoothDevice/BluetoothRemoteGATTServer/Service/
    Characteristic types. This is what should have caught the
    'gattservicedisconnected' typo fixed earlier — with real types in
    place, that name simply isn't assignable to addEventListener.
    Typing onDisconnected() also surfaced another live bug in the same
    vein: it read `event.target.device.name`, but gattserverdisconnected
    fires with event.target being the BluetoothDevice itself, not a
    wrapper with a .device property — so `.device` was always undefined
    and `.name` would have thrown. Fixed to read even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
2026-08-06 fix(controller-source): pin espressif32 platform, fix build
    `platform = espressif32` with no version resolved to the pioarduino
    fork's latest release (53.3.11, Arduino-ESP32 core 3.x / ESP-IDF 5.x),
    which failed to build:
    - ESP32TimerInterrupt uses the legacy driver/timer.h API, which is
    gone in ESP-IDF 5.x (TIMER_BASE_CLK undeclared, timer_config_t
    designator order mismatch).
    - Bluetooth.cpp assigned BLECharacteristic::getValue() (now returns
    Arduino String on this core) to a std::string, which no longer
    compiles.
    Pinned to platform = espressif32@6.5.0 (the official PlatformIO
    registry entry, Arduino-ESP32 core 2.x), which m5stack-stamps3 is
    still defined under and which both the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
2026-08-06 feat(web-app): redesign as a single dark, precision-instrument theme
    No live preview was available in this environment (the Chrome
    extension bridge didn't connect), so this is a code-level pass —
    please have a look and flag anything that needs adjusting.
    Why a rewrite instead of a coat of paint: the app's theme.scss defined
    a light and a dark variant, but nothing in the app ever set
    `body.light`/`body.dark` — so it was actually rendering the *light*
    block by default, which set --on-surface to white (white text on a
    light surface) everywhere except the one div with a hardcoded dark
    background. There was no theme toggle to reach the dark block at all.
    Rather than patch a broken theme noth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
2026-08-07 feat(web-app): persistent tracking sessions, CSV export, gap-aware chart
    Addresses a real problem with 24h unattended runs: the old model kept
    every BLE sample in one growing React array, copied whole on every
    ~520ms append with no cap — quadratic growth that would lock the tab
    up well before 24 hours (roughly 166k samples expected in a full run).
    It also held everything in memory only, so a reload or a dropped
    connection lost the whole session.
    No live preview was available in this environment again — please try
    a real (short) run and flag anything off.
    ## Storage (app/core/storage/db.ts)
    IndexedDB, no added dependency. Two stores: `trackings` (metadata +
    running min/max/sampleCount,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
2026-08-07 feat(web-app): dev tools for simulating a device and a 24h mock dataset
    Two buttons, top right of the topbar, both testing-only:
    - "Simulate Device" toggles a fake ~520ms-cadence feed (matching the
    firmware's real emit rate) into recordSample(), auto-starting a
    tracking first if none is active. Same code path a real BLE
    notification takes, so it exercises the live chart/stat tiles/status
    bands without hardware.
    - "Load 24h Mock" backfills a full 24h tracking in one shot: ~166k
    samples with realistic jitter, a slow drift in the nominal speed,
    and two disconnect-shaped gaps (~3min and ~18min) so it actually
    exercises the window selector, bucketing at scale, and the
    gap-detecti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
2026-08-28 chore: starting working on carrier board.
    [carrier-board.kicad_pcb, carrier-board.kicad_sch]
2026-08-28 test: add unit tests for web-app logic and controller-source RPM math
    Web app (web-app):
    - Add vitest + jsdom, npm test/test:watch scripts.
    - Unit tests for the pure chart logic (core/tracking/resample.ts:
    bucketing, averaging, gap detection, segmenting) and CSV export
    (core/tracking/csv.ts: formatting, sorting, filename sanitization,
    the DOM download flow).
    Controller source (controller-source):
    - Extract the tachometer edge-counting/RPM calculation out of
    arduino_target.ino's TimerHandler0, which was tightly coupled to
    digitalRead()/millis() and module-level volatile globals, into
    src/logic/RpmCounter -- a plain C++ class with no Arduino.h
    dependency. arduino_target.ino now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
    [arduino_target.ino]
2026-08-28 fix(controller-source): restore ISR-safety and default-build correctness in RpmCounter
    Three issues from /code-review, all reproduced directly before fixing:
    - rpm_ lost the `volatile` it had as a global (`volatile float RPM`)
    even though it's written from the TimerHandler0 ISR and read from
    emitRPMLoop on the other task -- without it the compiler is free to
    cache a stale value across that task's polling loop.
    - update()/completeRevolution() are called from the IRAM_ATTR ISR but
    compiled in a separate translation unit without IRAM_ATTR
    themselves, unlike the original logic that was fully inlined inside
    the IRAM-resident ISR. Code reached from an IRAM ISR that isn't
    itself IRA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
2026-08-28 chore: Updated docs.
    [astreaus_body_v1.stl, astreaus_bottom_v1.stl, astreaus_led_v1.stl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]
2026-08-28 feat(web-app): name/rename trackings, move BLE status to topbar, fix chart & session correctness
    Naming:
    - Optional name field next to Start Tracking; blank falls back to the
    existing auto-generated "Tracking — <date>".
    - Rename any tracking (active or stopped) via a new edit icon in the
    Trackings list. Adds db.renameTracking + TrackingContext.renameTracking.
    Layout:
    - Moved the BLE connect status/button from the fixed footer into the
    topbar (top right). Removed the footer entirely, including the fixed
    bottom-bar padding reservation in dashboard.scss.
    Bug fixes:
    - Avg stat was NaN: the earlier Min->Avg migration's "already migrated?"
    guard used `typeof sum === 'number'`, which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
2026-10-05 fix(web-app): record samples for trackings started after pairing, detect Bluetooth off
    The characteristic listener captured recordSample from the render at
    pairing time, when activeTrackingId was still null, so a tracking
    started afterwards never persisted samples and the chart stayed empty
    until a refresh + re-pair. Call it through a ref so it always sees the
    current tracking (also fixes samples going to a stopped tracking after
    stop/start while connected).
    Also check navigator.bluetooth.getAvailability() on load, on
    availabilitychanged and before opening the picker, showing a "Bluetooth
    is turned off" status and disabling the connect button instead of an
    empty device picker.
    Co-Authored-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
2026-10-12 chore(web-app): update deps, migrate to ESLint 10, improve SEO and performance
    Dependencies
    - React 19, MUI 9, visx 4, BeerCSS 5, TypeScript 5.9, Vitest 5, jsdom 29,
    Babel 8 (@babel/eslint-parser + @babel/core), and in-range updates.
    - Enable Parcel packageExports: MUI 7+ only exposes ESM via "exports", so
    Parcel fell back to CJS and bundled all of MUI (1.55 MB -> 458 kB JS).
    - Replace moment with small native helpers (time.ts) matching its output.
    - Use Yarn only (drop package-lock.json); pin Node 24.11.0 / Yarn 1.22.22
    via Volta so the global Yarn 4 doesn't rewrite the v1 lockfile.
    - Remove unused stylelint (sole source of the unpatched braces advisory),
    the eslint-8-only tslint pl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
2026-10-18 feat(web-app): app-style layout with menu bar, turntable folders and run comparison
    - Menu bar (File / Measurement / View), New measurement / Stop button and
    BLE status; collapses to an overflow menu on phones
    - Library sidebar grouping measurements into folders per turntable
    (model + serial number), with search, per-row actions and compare
    checkboxes; overlay drawer below 900px
    - Dialogs for new measurement (pick or create turntable, reuses an
    existing name+serial match), folders, rename, move and delete
    - Compare view: up to 8 runs overlaid by elapsed time, hover tooltip,
    legend and stats table (mean, drift, std dev, min, max at speed)
    - IndexedDB v4 adds a folders store; existin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
2026-10-18 docs: new enclosure parts with chassis spacer, renders and updated README
    - Update spindex_bottom.stl and spindex_top.stl; add spindex_spacer.stl,
    an optional insert for the other chassis width of Beogram
    4000/4002/4004 variants
    - Add exploded and assembled renders of the enclosure
    - Rewrite the web-app section of the README for the current app and add
    fresh measurement and comparison screenshots
2026-10-24 feat(controller): send readings over the StampS3's USB-C port
    Serial was going to UART0 (G43/G44), which nothing is wired to. Enable
    CDC-on-boot so it reaches the USB-C port (the ESP32-S3's built-in
    USB-Serial/JTAG), where the web app reads it over Web Serial.
    - Print each reading as one `rpm:33.33` line, in a single write, so the
    app can skip debug output and spot lines cut short by a full buffer.
    - A 10ms TX timeout keeps a host that isn't reading from stalling the
    loop that also sends the Bluetooth notifications.
    - scripts/restore_tty.py resets the port to VMIN=1 after each upload on
    Linux: pyserial tools leave VMIN=0, which Chrome before Chromium's
    2026-09 fix reads as the devic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
2026-10-24 feat(web-app): connect over USB (Web Serial) as well as Bluetooth (v2.2.0)
    The connection menu (top right) offers Bluetooth or USB cable. Only the
    picked link's readings are recorded, and picking the other drops it.
    USB widens recording to Chrome on Linux without a flag, Firefox 151+ and
    Opera on desktop.
    - BLEContext becomes LinkContext: useBluetoothLink (the existing code,
    plus disconnect) and a new useSerialLink, behind one context.
    - USB reconnects when a cable pulled mid-session is plugged back in, and
    on a reload during a recording. An idle tab leaves the port alone, and
    a port that sends no readings for 10s is released, so an open tab
    doesn't block flashing.
    - Stale connect a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
2026-10-24 feat(controller): report the firmware version on connecting
    The sensor now says which firmware it runs, over both links:
    - Bluetooth: the standard Device Information Service (0x180A) with the
    Firmware Revision String (0x2A26), next to the existing RPM service.
    - USB: a `version` line from the host is answered with a line like
    `version:2.3.0`, also printed on startup, so a host already reading
    when the sensor restarts learns it too. Lines are read in loop().
    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
2026-10-24 feat(web-app): show the sensor's firmware version (v2.3.0)
    The status bar shows the connected sensor's firmware version, read on
    every (re)connection over Bluetooth and on opening the port over USB.
    - Bluetooth reads the Device Information Service's Firmware Revision
    String. Firmware without it connects as before.
    - USB sends `version` on opening, and once more with the first reading
    if no answer has come. The parser now reads lines during the settle
    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
2026-10-24 fix: harden firmware version reporting, and simplify it
    From /simplify and /code-review of the firmware version work:
    - Bluetooth: a link that drops during the version read is no longer
    marked connected (the read's failure hid the drop, and reset the
    reconnect backoff). A missing Device Information Service gives up at
    once; any other failed read is tried once more.
    - "Firmware unknown" no longer claims the firmware is old: it may just
    not have answered.
    - USB: requestFirmwareVersion never rejects, the version state is only
    set when it changes, and the parser's stale-line check is one start
    time per line instead of three flags.
    - Firmware: CR alone also ends a line, so `version`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
